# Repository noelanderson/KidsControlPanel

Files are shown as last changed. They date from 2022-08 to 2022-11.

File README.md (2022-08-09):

# KidsControlPanel
Octonaut's inspired vehicle control panel with flight yoke and standard instruments

Javascript application runs instrument cluster on Raspberry Pi displaying on a (800x400) lcd panel

Custom RP2040 based hardware runs the remaining panel functions

RP2040 board appears as a HID joystick and uses a VL6180X ranging sensor to measure pitch, and an AS5600 magnetic Rotation Sensor to measure roll.

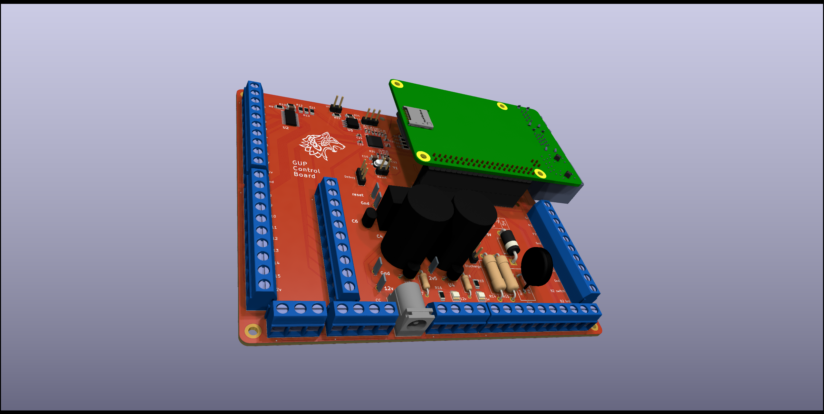
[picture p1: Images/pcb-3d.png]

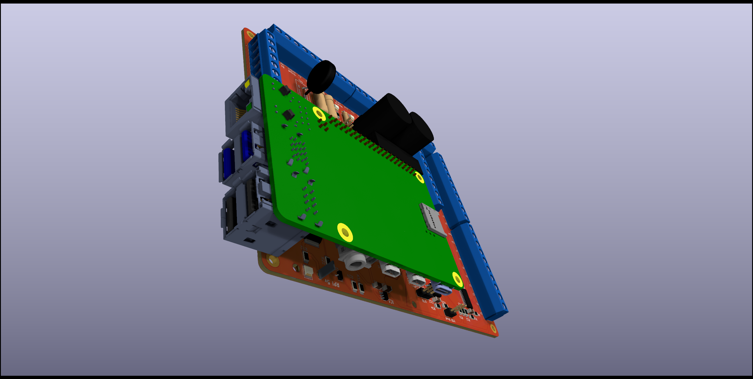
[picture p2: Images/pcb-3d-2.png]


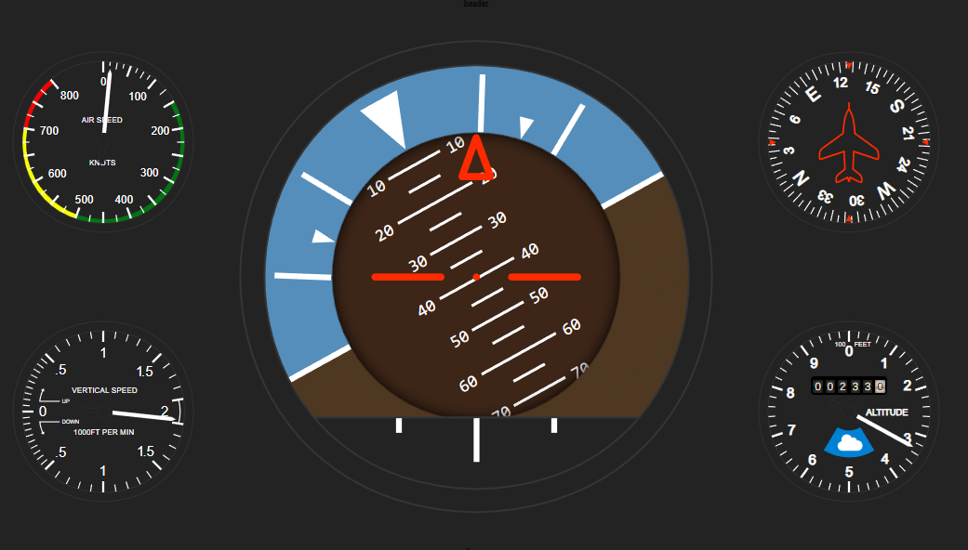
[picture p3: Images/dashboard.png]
dashboard


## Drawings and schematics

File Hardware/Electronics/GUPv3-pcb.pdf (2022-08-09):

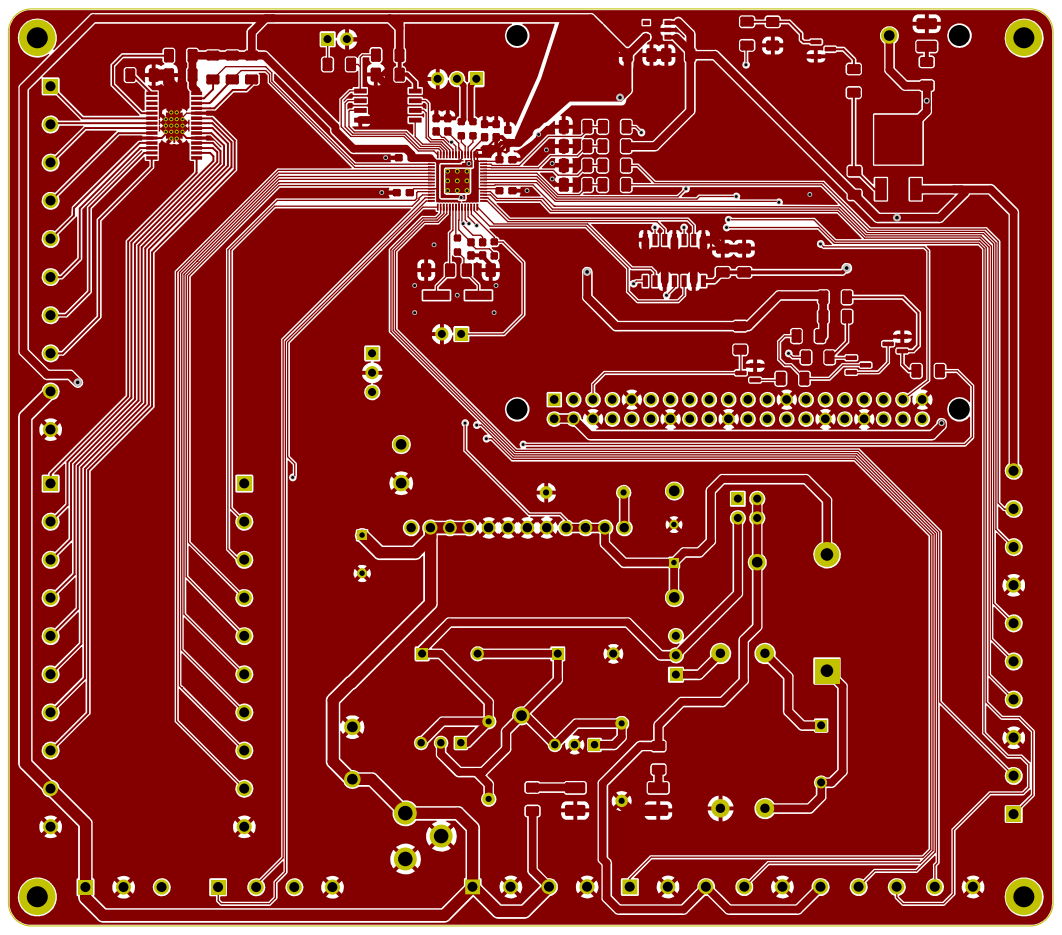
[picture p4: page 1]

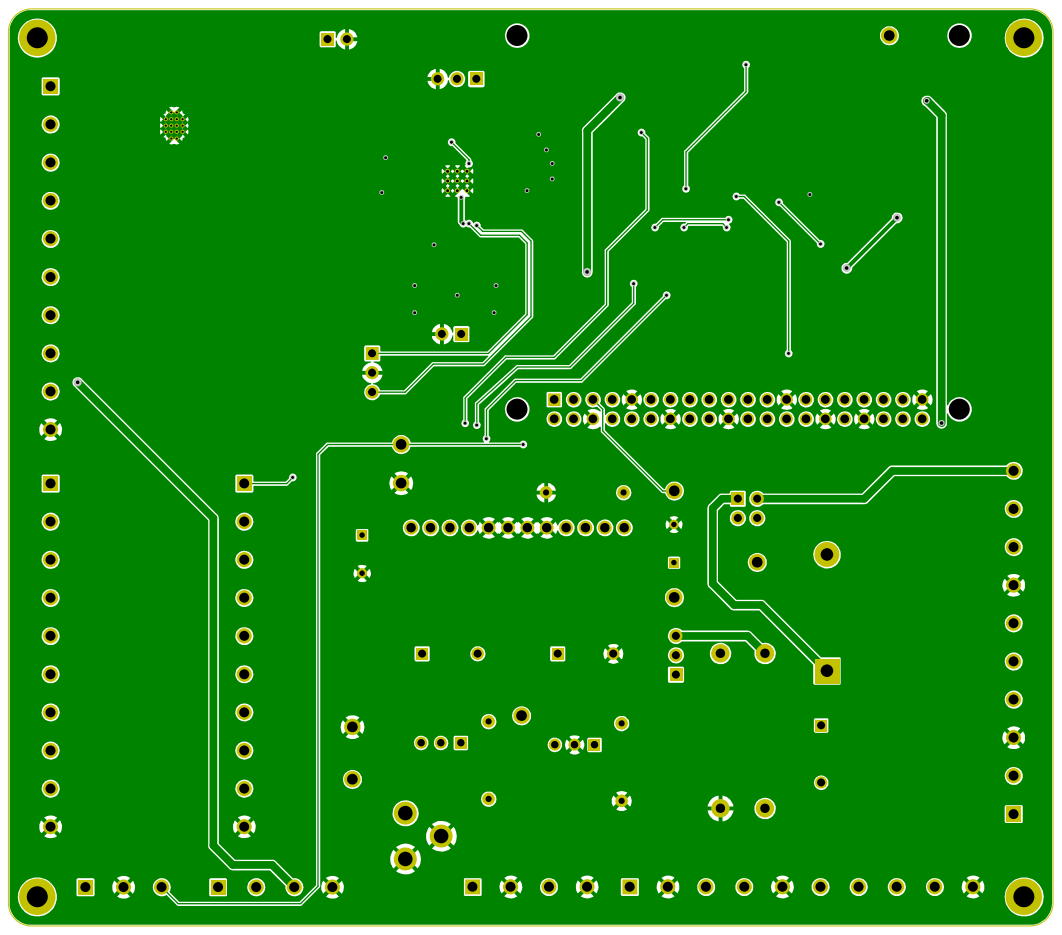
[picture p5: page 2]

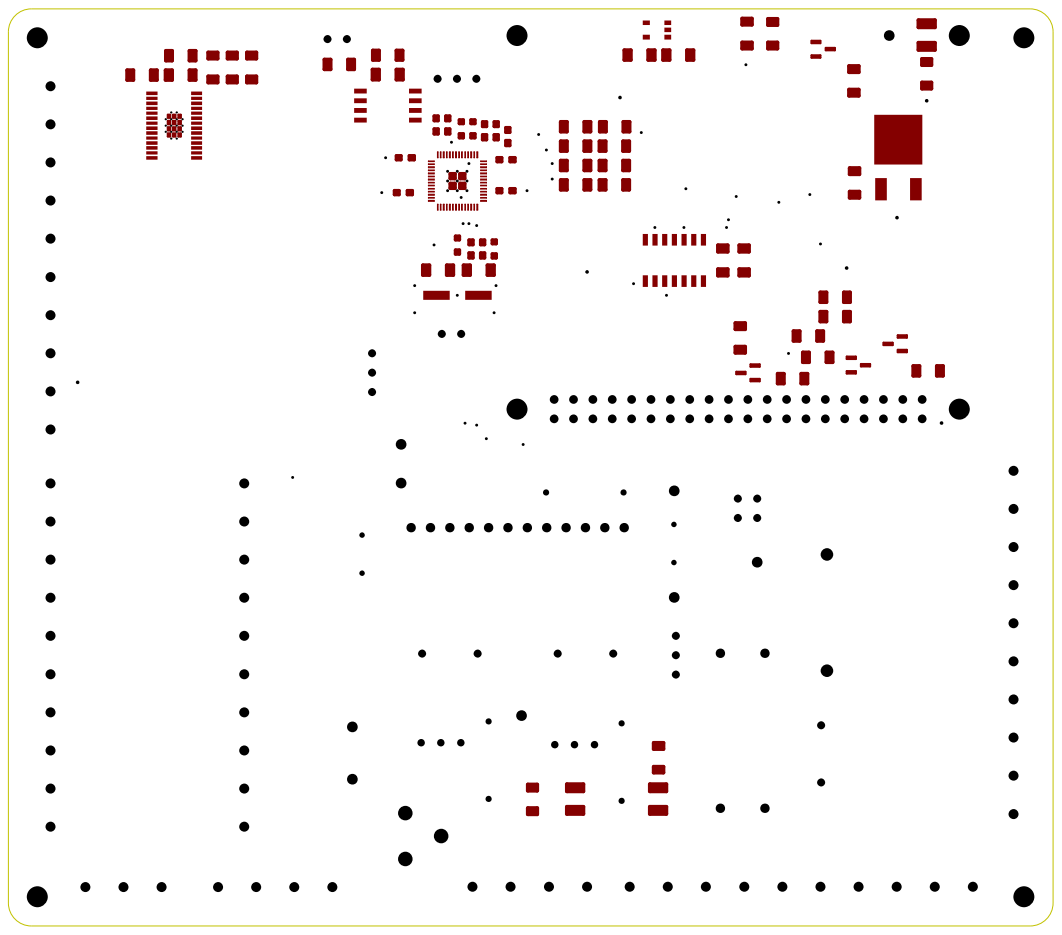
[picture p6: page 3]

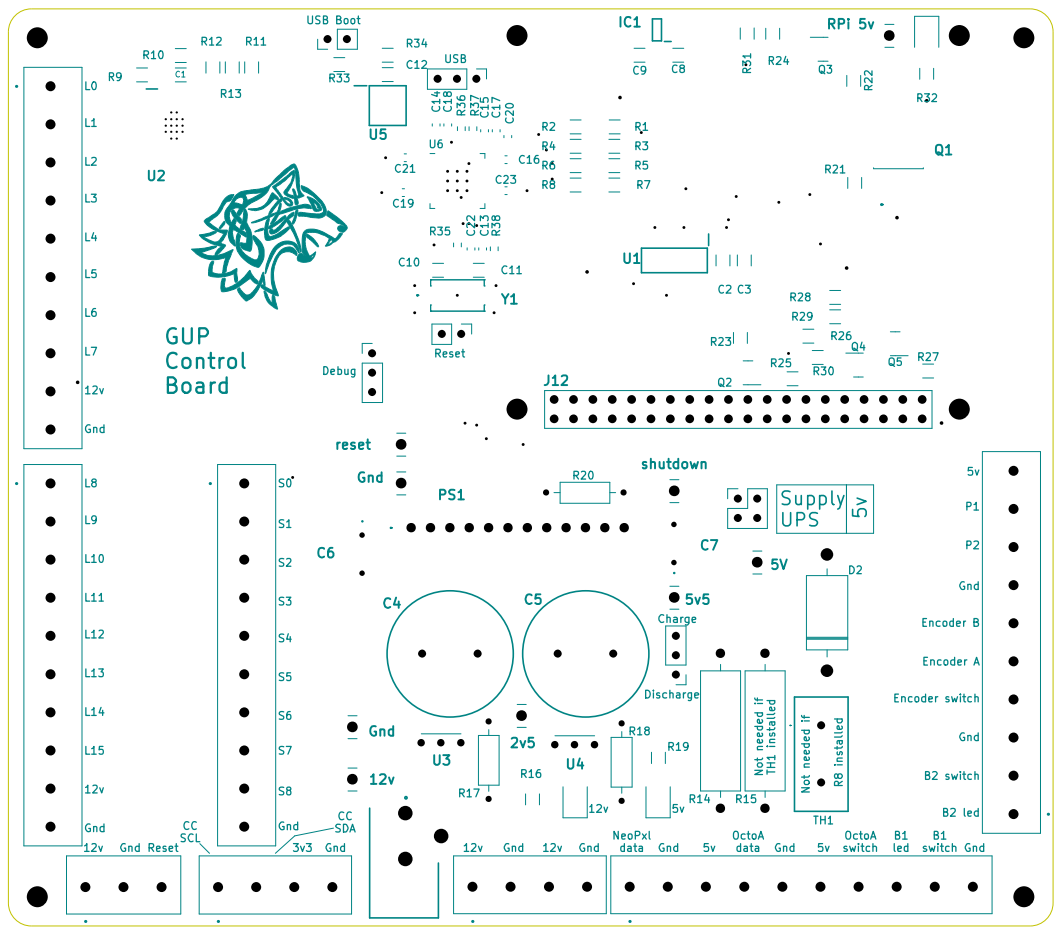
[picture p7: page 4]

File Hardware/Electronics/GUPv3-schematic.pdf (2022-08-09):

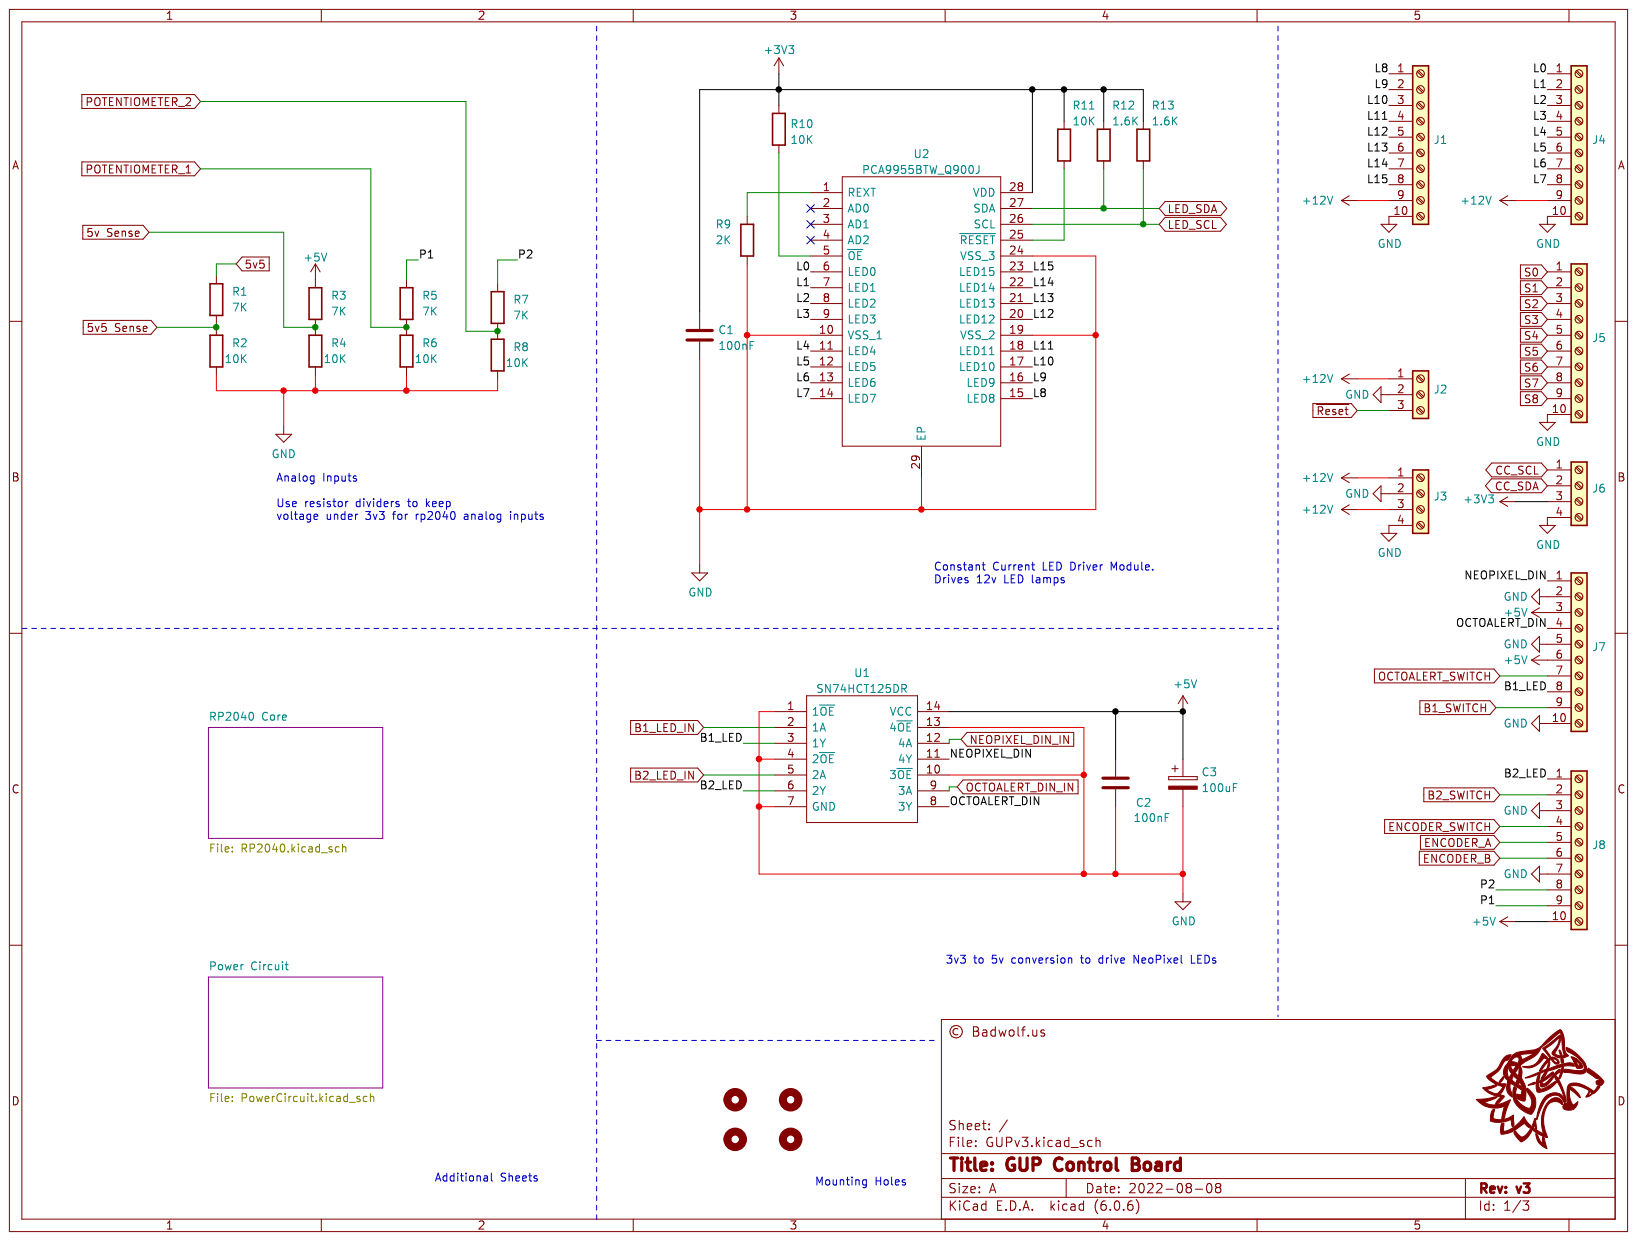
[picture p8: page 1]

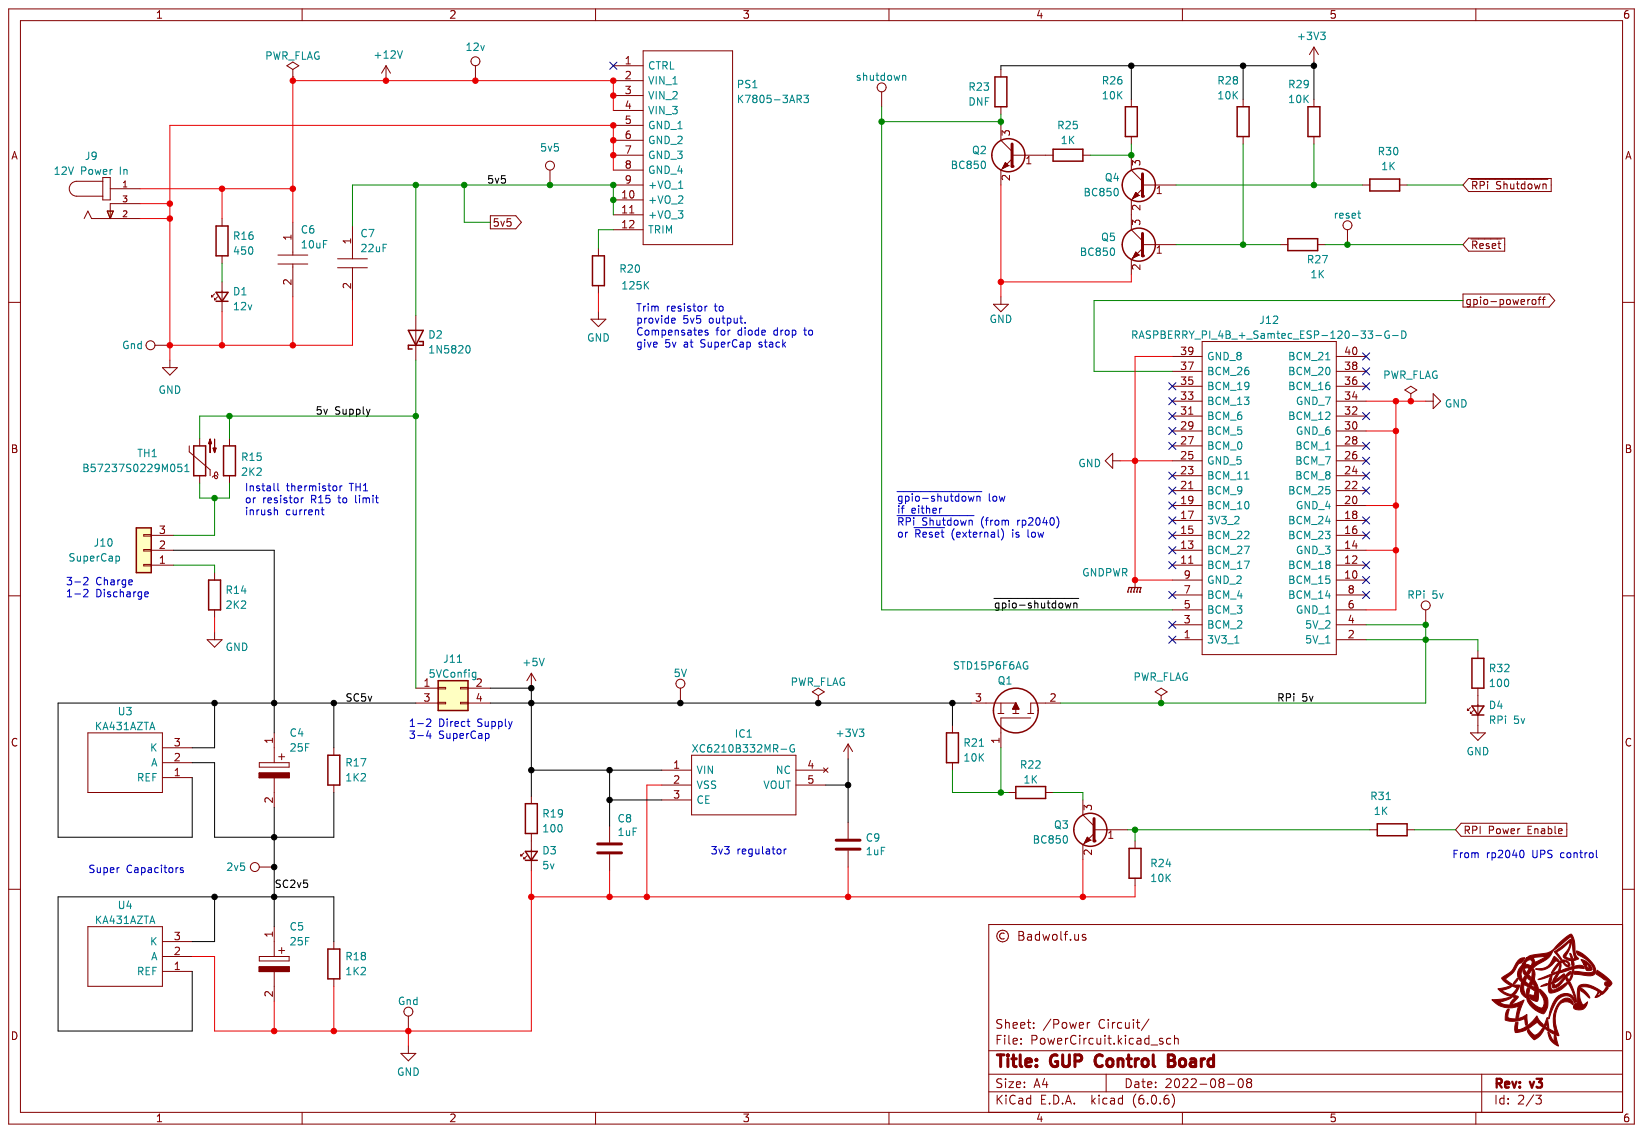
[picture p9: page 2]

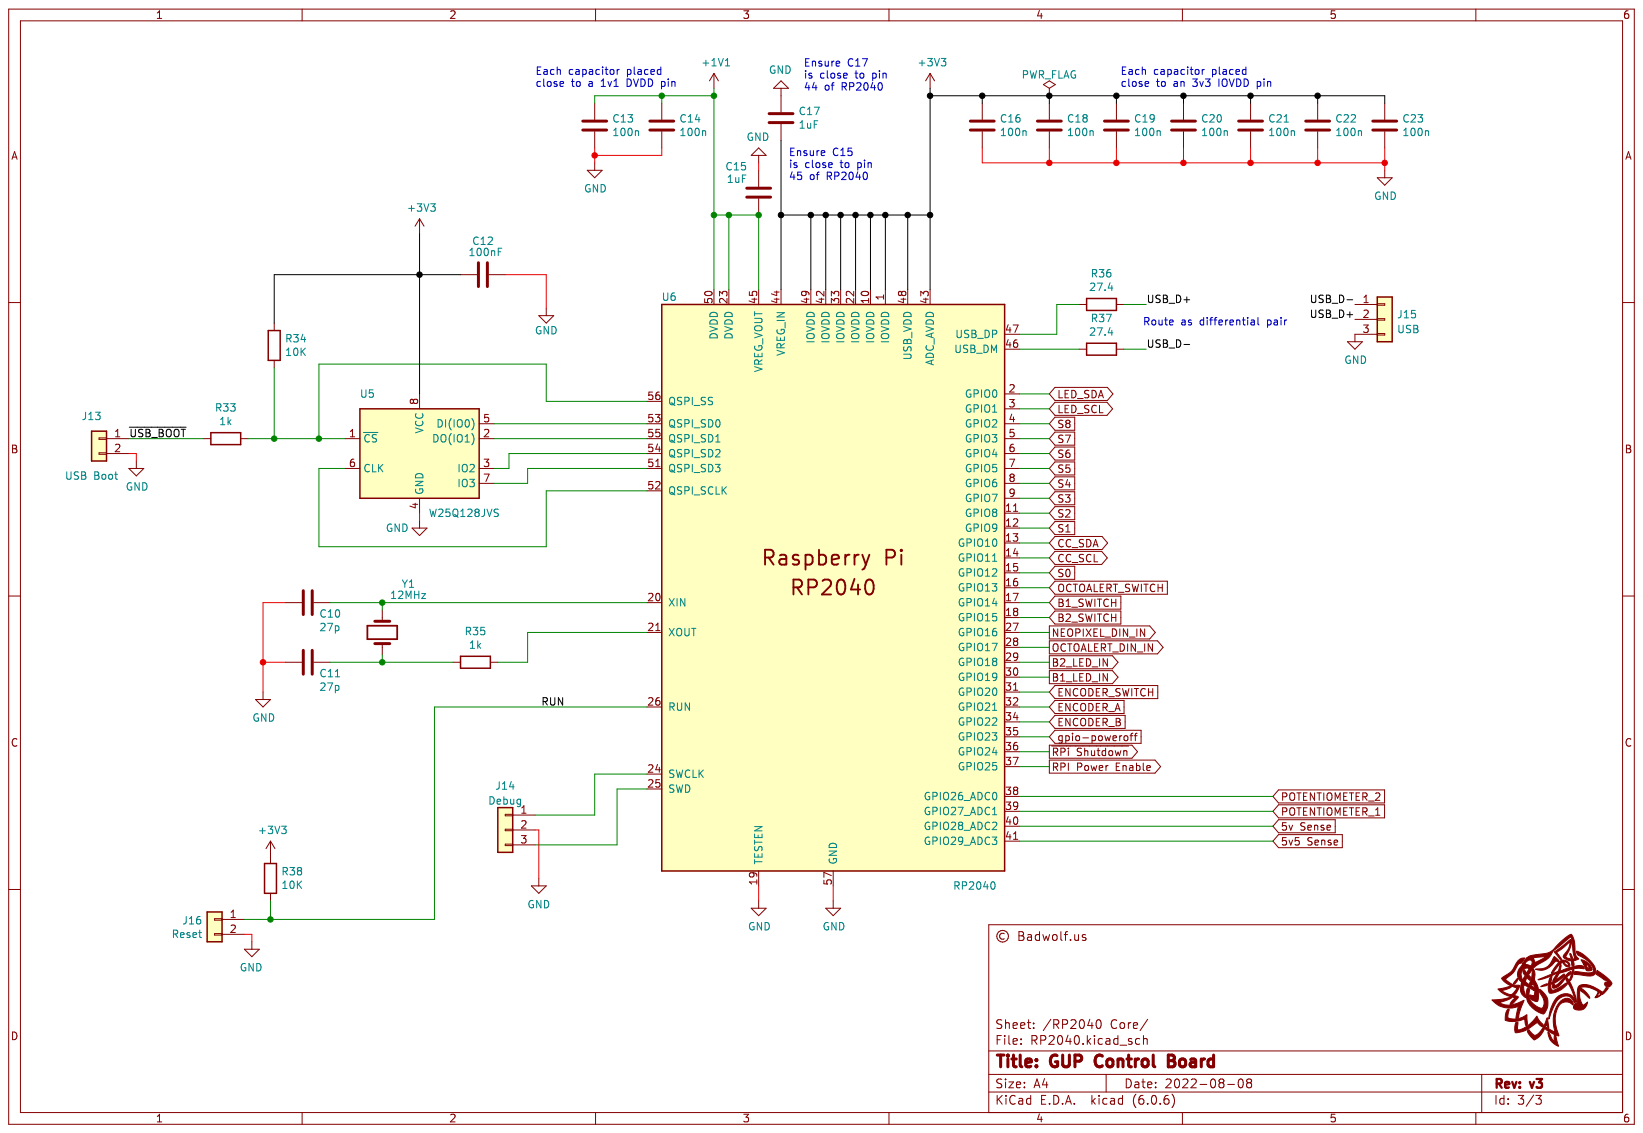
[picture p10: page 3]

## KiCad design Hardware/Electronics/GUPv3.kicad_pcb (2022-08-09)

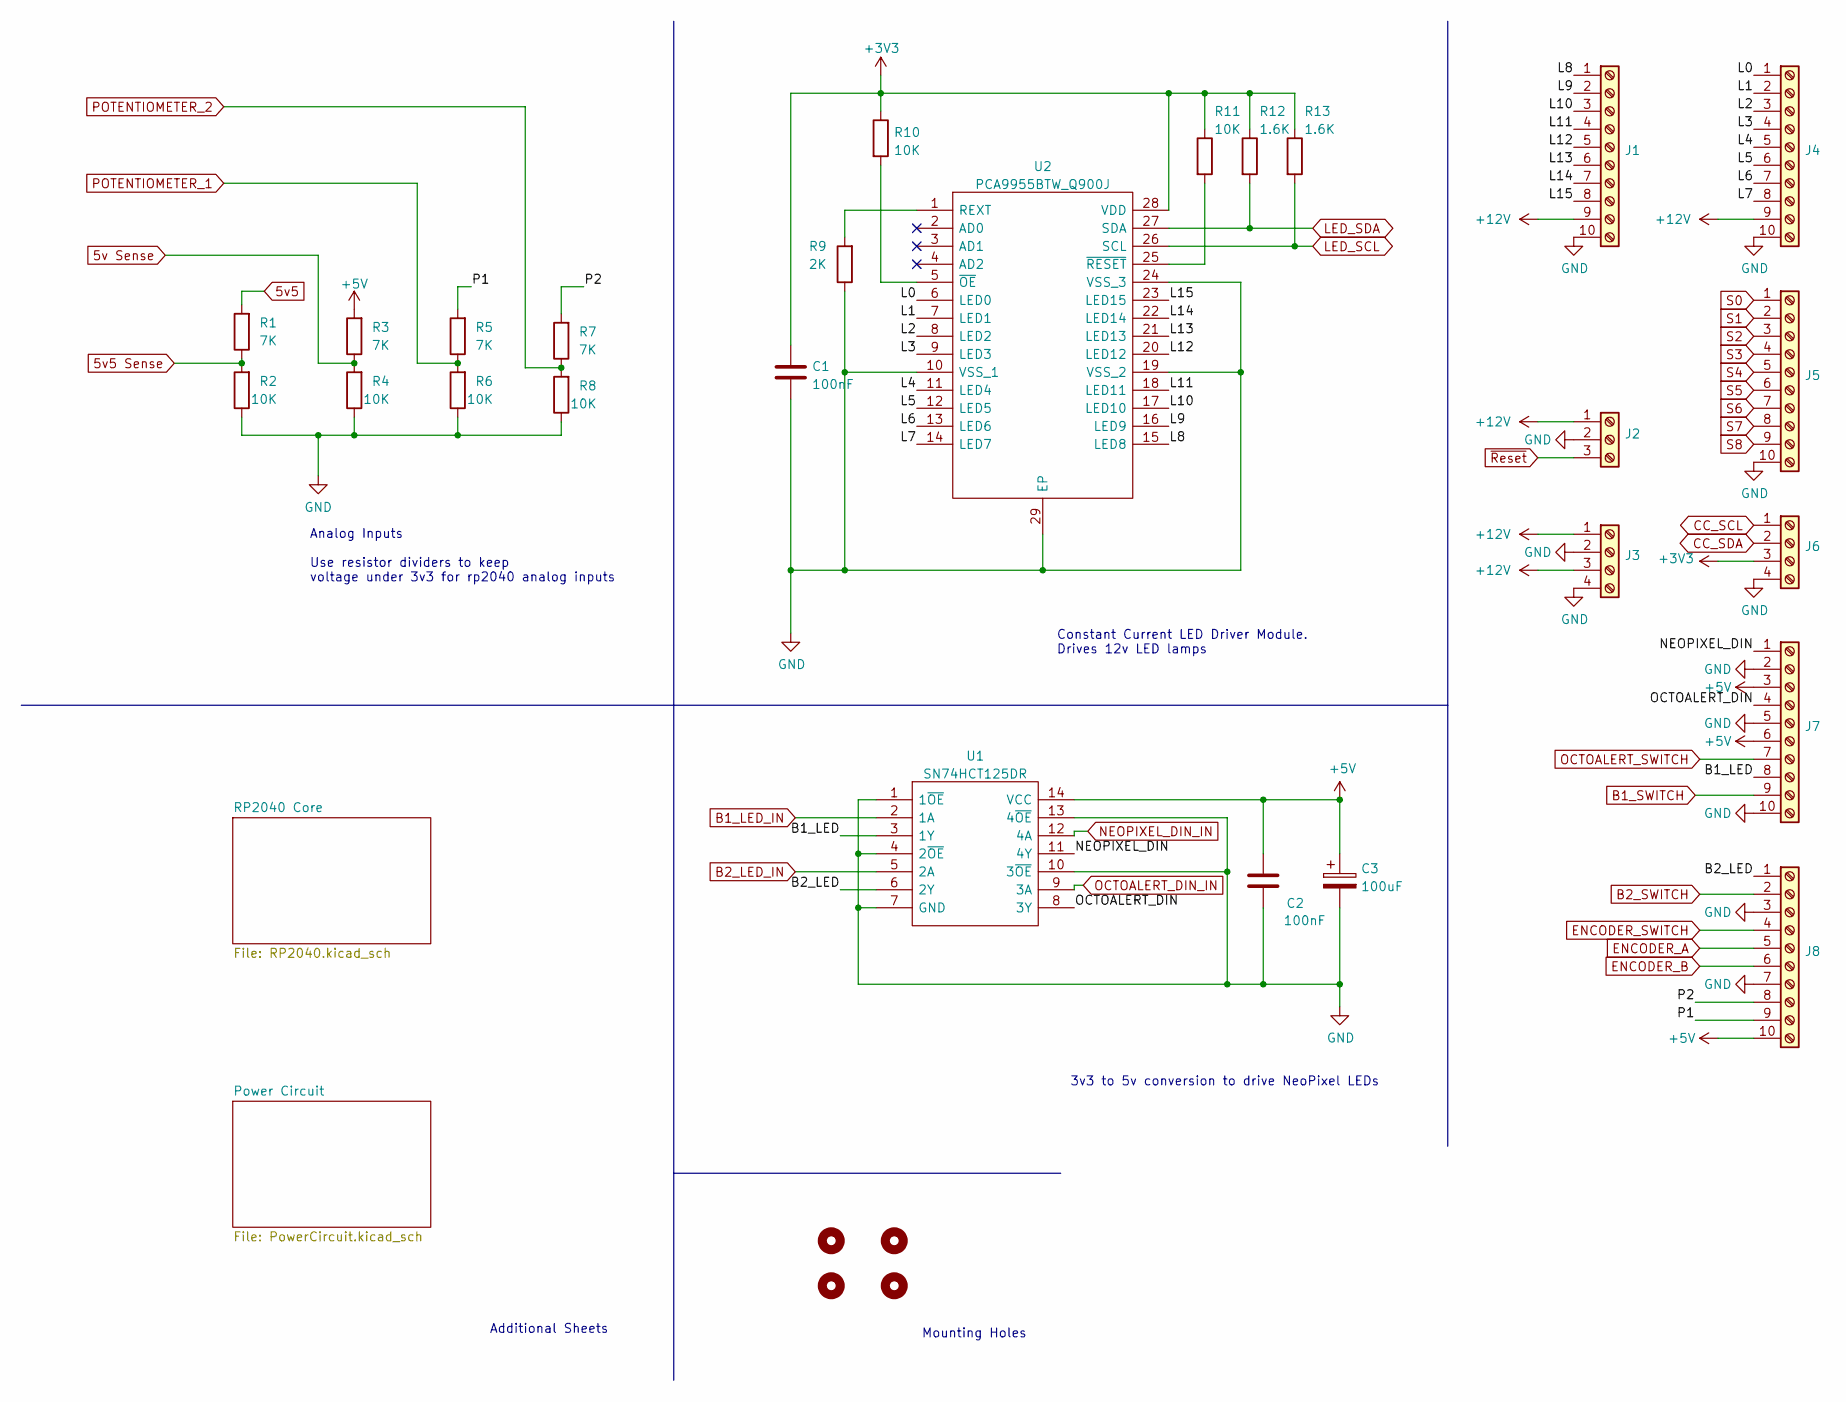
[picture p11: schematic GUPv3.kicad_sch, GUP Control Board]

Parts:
C1, C2: 100nF; C_1206_3216Metric_Pad1.33x1.80mm_HandSolder
C3: 100uF; C_1206_3216Metric_Pad1.33x1.80mm_HandSolder
H1, H2, H3, H4: M2.5; MountingHole_2.7mm_M2.5_DIN965_Pad
J1, J4, J5, J7, J8: Screw_Terminal_01x10; CUI_TB002-500-10BE
J2: Screw_Terminal_01x03; CUI_TB002-500-03BE
J3, J6: Screw_Terminal_01x04; CUI_TB002-500-04BE
R1, R3, R5, R7: 7K; R_1206_3216Metric_Pad1.30x1.75mm_HandSolder
R2, R4, R6, R8, R10, R11: 10K; R_1206_3216Metric_Pad1.30x1.75mm_HandSolder
R9: 2K; R_1206_3216Metric_Pad1.30x1.75mm_HandSolder
R12, R13: 1.6K; R_1206_3216Metric_Pad1.30x1.75mm_HandSolder
U1: SN74HCT125DR; SOIC127P600X175-14N; Mouser Part Number 595-SN74HCT125DR
U2: PCA9955BTW_Q900J; SOP65P640X110-29N_thermal_vias; Mouser Part Number 771-PCA9955BTW/Q900J

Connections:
5v5: R1.2; also elsewhere on the board
5v5 Sense: R1.1, R2.2; also elsewhere on the board
5v Sense: R3.1, R4.2; also elsewhere on the board
+3V3: C1.1, J6.3, R10.1, R11.1, R12.1, R13.1, U2.28 (VDD); also elsewhere on the board
+5V: C2.1, C3.1, J7.3, J7.6, J8.10, R3.2, U1.14 (VCC); also elsewhere on the board
+12V: J1.9, J2.1, J3.1, J3.3, J4.9; also elsewhere on the board
/B1_LED: J7.8, U1.3 (1Y)
/B2_LED: J8.1, U1.6 (2Y)
/L0: J4.1, U2.6 (LED0)
/L1: J4.2, U2.7 (LED1)
/L2: J4.3, U2.8 (LED2)
/L3: J4.4, U2.9 (LED3)
/L4: J4.5, U2.11 (LED4)
/L5: J4.6, U2.12 (LED5)
/L6: J4.7, U2.13 (LED6)
/L7: J4.8, U2.14 (LED7)
/L8: J1.1, U2.15 (LED8)
/L9: J1.2, U2.16 (LED9)
/L10: J1.3, U2.17 (LED10)
/L11: J1.4, U2.18 (LED11)
/L12: J1.5, U2.20 (LED12)
/L13: J1.6, U2.21 (LED13)
/L14: J1.7, U2.22 (LED14)
/L15: J1.8, U2.23 (LED15)
/NEOPIXEL_DIN: J7.1, U1.11 (4Y)
/OCTOALERT_DIN: J7.4, U1.8 (3Y)
/P1: J8.9, R5.2
/P2: J8.8, R7.2
B1_LED_IN: U1.2 (1A); also elsewhere on the board
B1_SWITCH: J7.9; also elsewhere on the board
B2_LED_IN: U1.5 (2A); also elsewhere on the board
B2_SWITCH: J8.2; also elsewhere on the board
CC_SCL: J6.1; also elsewhere on the board
CC_SDA: J6.2; also elsewhere on the board
ENCODER_A: J8.5; also elsewhere on the board
ENCODER_B: J8.6; also elsewhere on the board
ENCODER_SWITCH: J8.4; also elsewhere on the board
GND: C1.2, C2.2, C3.2, J1.10, J2.2, J3.2, J3.4, J4.10, J5.10, J6.4, J7.2, J7.5, J7.10, J8.3, J8.7, R2.1, R4.1, R6.1, R8.1, R9.1, U1.1 (1~OE), U1.4 (2~OE), U1.7 (GND), U1.10 (3~OE), U1.13 (4~OE), U2.10 (VSS_1), U2.19 (VSS_2), U2.24 (VSS_3), U2.29 (EP); also elsewhere on the board
LED_SCL: R13.2, U2.26 (SCL); also elsewhere on the board
LED_SDA: R12.2, U2.27 (SDA); also elsewhere on the board
NEOPIXEL_DIN_IN: U1.12 (4A); also elsewhere on the board
unnamed: R9.2, U2.1 (REXT)
unnamed: R10.2, U2.5 (~OE)
unnamed: R11.2, U2.25 (~RESET)
OCTOALERT_DIN_IN: U1.9 (3A); also elsewhere on the board
OCTOALERT_SWITCH: J7.7; also elsewhere on the board
POTENTIOMETER_1: R5.1, R6.2; also elsewhere on the board
POTENTIOMETER_2: R7.1, R8.2; also elsewhere on the board
S0: J5.1; also elsewhere on the board
S1: J5.2; also elsewhere on the board
S2: J5.3; also elsewhere on the board
S3: J5.4; also elsewhere on the board
S4: J5.5; also elsewhere on the board
S5: J5.6; also elsewhere on the board
S6: J5.7; also elsewhere on the board
S7: J5.8; also elsewhere on the board
S8: J5.9; also elsewhere on the board
~Reset: J2.3; also elsewhere on the board

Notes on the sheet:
3v3 to 5v conversion to drive NeoPixel LEDs
Analog Inputs Use resistor dividers to keep voltage under 3v3 for rp2040 analog inputs
Constant Current LED Driver Module. Drives 12v LED lamps
Additional Sheets
Mounting Holes

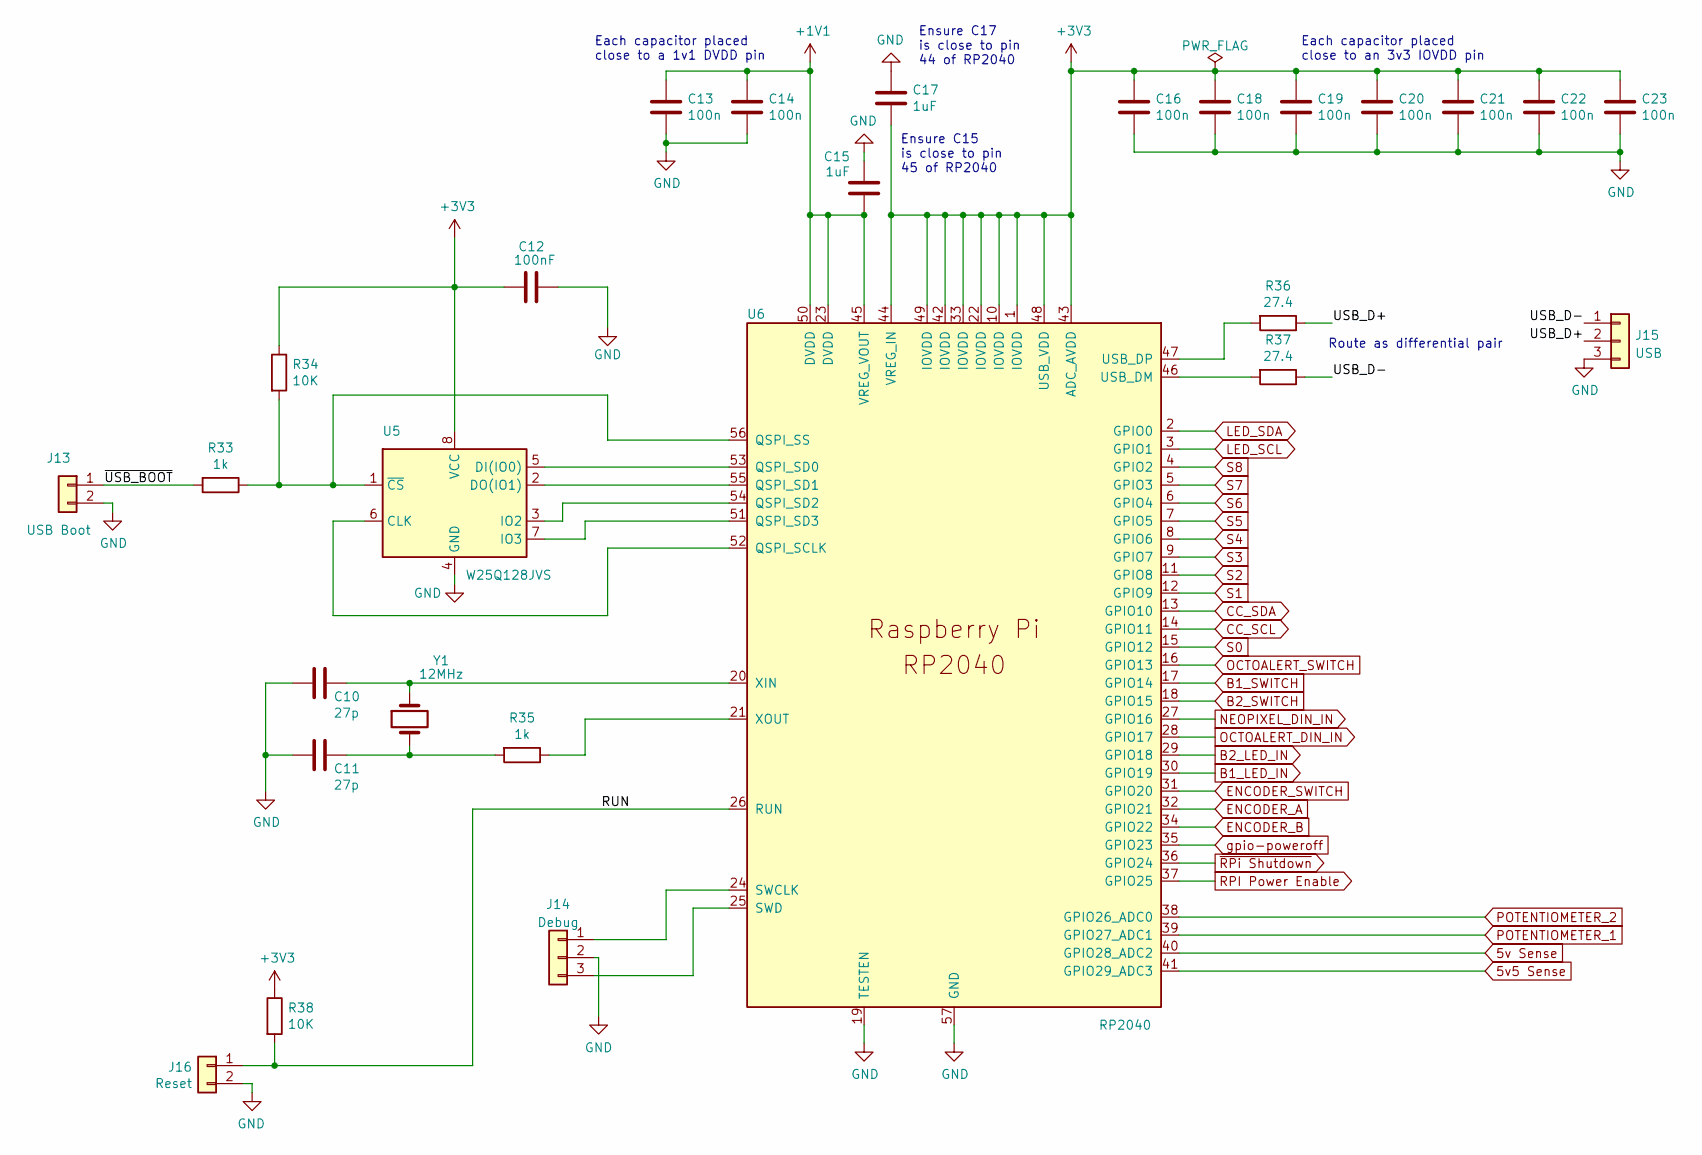
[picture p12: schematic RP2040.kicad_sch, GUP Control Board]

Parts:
C10, C11: 27p; C_1206_3216Metric_Pad1.33x1.80mm_HandSolder
C12: 100nF; C_1206_3216Metric_Pad1.33x1.80mm_HandSolder
C13, C14, C16, C18, C19, C20, C21, C22, C23: 100n; C_0603_1608Metric_Pad1.08x0.95mm_HandSolder
C15, C17: 1uF; C_0603_1608Metric_Pad1.08x0.95mm_HandSolder
J13: USB Boot; PinHeader_1x02_P2.54mm_Vertical
J14: Debug; PinHeader_1x03_P2.54mm_Vertical
J15: USB; PinHeader_1x03_P2.54mm_Vertical
J16: Reset; PinHeader_1x02_P2.54mm_Vertical
R33: 1k; R_1206_3216Metric_Pad1.30x1.75mm_HandSolder
R34: 10K; R_1206_3216Metric_Pad1.30x1.75mm_HandSolder
R35: 1k; R_0603_1608Metric_Pad0.98x0.95mm_HandSolder
R36, R37: 27.4; R_0603_1608Metric_Pad0.98x0.95mm_HandSolder
R38: 10K; R_0603_1608Metric_Pad0.98x0.95mm_HandSolder
U5: W25Q128JVS; SOIC127P790X216-8N
U6: RP2040; RP2040-QFN-56
Y1: 12MHz; ABLS7M216000MHZD2YT; Digi-Key_PN 535-13415-1-ND

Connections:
5v5 Sense: U6.41 (GPIO29_ADC3); also elsewhere on the board
5v Sense: U6.40 (GPIO28_ADC2); also elsewhere on the board
+1V1: C13.1, C14.1, C15.1, U6.23 (DVDD), U6.45 (VREG_VOUT), U6.50 (DVDD)
+3V3: C12.2, C16.1, C17.2, C18.1, C19.1, C20.1, C21.1, C22.1, C23.1, R34.1, R38.1, U5.8 (VCC), U6.1 (IOVDD), U6.10 (IOVDD), U6.22 (IOVDD), U6.33 (IOVDD), U6.42 (IOVDD), U6.43 (ADC_AVDD), U6.44 (VREG_IN), U6.48 (USB_VDD), U6.49 (IOVDD); also elsewhere on the board
/RP2040 Core/RUN: J16.1, R38.2, U6.26 (RUN)
/RP2040 Core/USB_D+: J15.2, R36.1
/RP2040 Core/USB_D-: J15.1, R37.1
/RP2040 Core/~USB_BOOT: J13.1, R33.2
B1_LED_IN: U6.30 (GPIO19); also elsewhere on the board
B1_SWITCH: U6.17 (GPIO14); also elsewhere on the board
B2_LED_IN: U6.29 (GPIO18); also elsewhere on the board
B2_SWITCH: U6.18 (GPIO15); also elsewhere on the board
CC_SCL: U6.14 (GPIO11); also elsewhere on the board
CC_SDA: U6.13 (GPIO10); also elsewhere on the board
ENCODER_A: U6.32 (GPIO21); also elsewhere on the board
ENCODER_B: U6.34 (GPIO22); also elsewhere on the board
ENCODER_SWITCH: U6.31 (GPIO20); also elsewhere on the board
GND: C10.2, C11.2, C12.1, C13.2, C14.2, C15.2, C16.2, C17.1, C18.2, C19.2, C20.2, C21.2, C22.2, C23.2, J13.2, J14.2, J15.3, J16.2, U5.4 (GND), U6.19 (TESTEN), U6.57 (GND); also elsewhere on the board
LED_SCL: U6.3 (GPIO1); also elsewhere on the board
LED_SDA: U6.2 (GPIO0); also elsewhere on the board
NEOPIXEL_DIN_IN: U6.27 (GPIO16); also elsewhere on the board
unnamed: C10.1, U6.20 (XIN), Y1.1
unnamed: C11.1, R35.2, Y1.2
unnamed: J14.1, U6.24 (SWCLK)
unnamed: J14.3, U6.25 (SWD)
unnamed: R33.1, R34.2, U5.1 (~CS), U6.56 (QSPI_SS)
unnamed: R35.1, U6.21 (XOUT)
unnamed: R36.2, U6.47 (USB_DP)
unnamed: R37.2, U6.46 (USB_DM)
unnamed: U5.2 (DO(IO1)), U6.55 (QSPI_SD1)
unnamed: U5.3 (IO2), U6.54 (QSPI_SD2)
unnamed: U5.5 (DI(IO0)), U6.53 (QSPI_SD0)
unnamed: U5.6 (CLK), U6.52 (QSPI_SCLK)
unnamed: U5.7 (IO3), U6.51 (QSPI_SD3)
OCTOALERT_DIN_IN: U6.28 (GPIO17); also elsewhere on the board
OCTOALERT_SWITCH: U6.16 (GPIO13); also elsewhere on the board
POTENTIOMETER_1: U6.39 (GPIO27_ADC1); also elsewhere on the board
POTENTIOMETER_2: U6.38 (GPIO26_ADC0); also elsewhere on the board
RPI Power Enable: U6.37 (GPIO25); also elsewhere on the board
S0: U6.15 (GPIO12); also elsewhere on the board
S1: U6.12 (GPIO9); also elsewhere on the board
S2: U6.11 (GPIO8); also elsewhere on the board
S3: U6.9 (GPIO7); also elsewhere on the board
S4: U6.8 (GPIO6); also elsewhere on the board
S5: U6.7 (GPIO5); also elsewhere on the board
S6: U6.6 (GPIO4); also elsewhere on the board
S7: U6.5 (GPIO3); also elsewhere on the board
S8: U6.4 (GPIO2); also elsewhere on the board
gpio-poweroff: U6.35 (GPIO23); also elsewhere on the board
~RPi Shutdown: U6.36 (GPIO24); also elsewhere on the board

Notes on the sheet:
Route as differential pair
Ensure C15 is close to pin 45 of RP2040
Each capacitor placed close to an 3v3 IOVDD pin
Ensure C17 is close to pin 44 of RP2040
Each capacitor placed close to a 1v1 DVDD pin

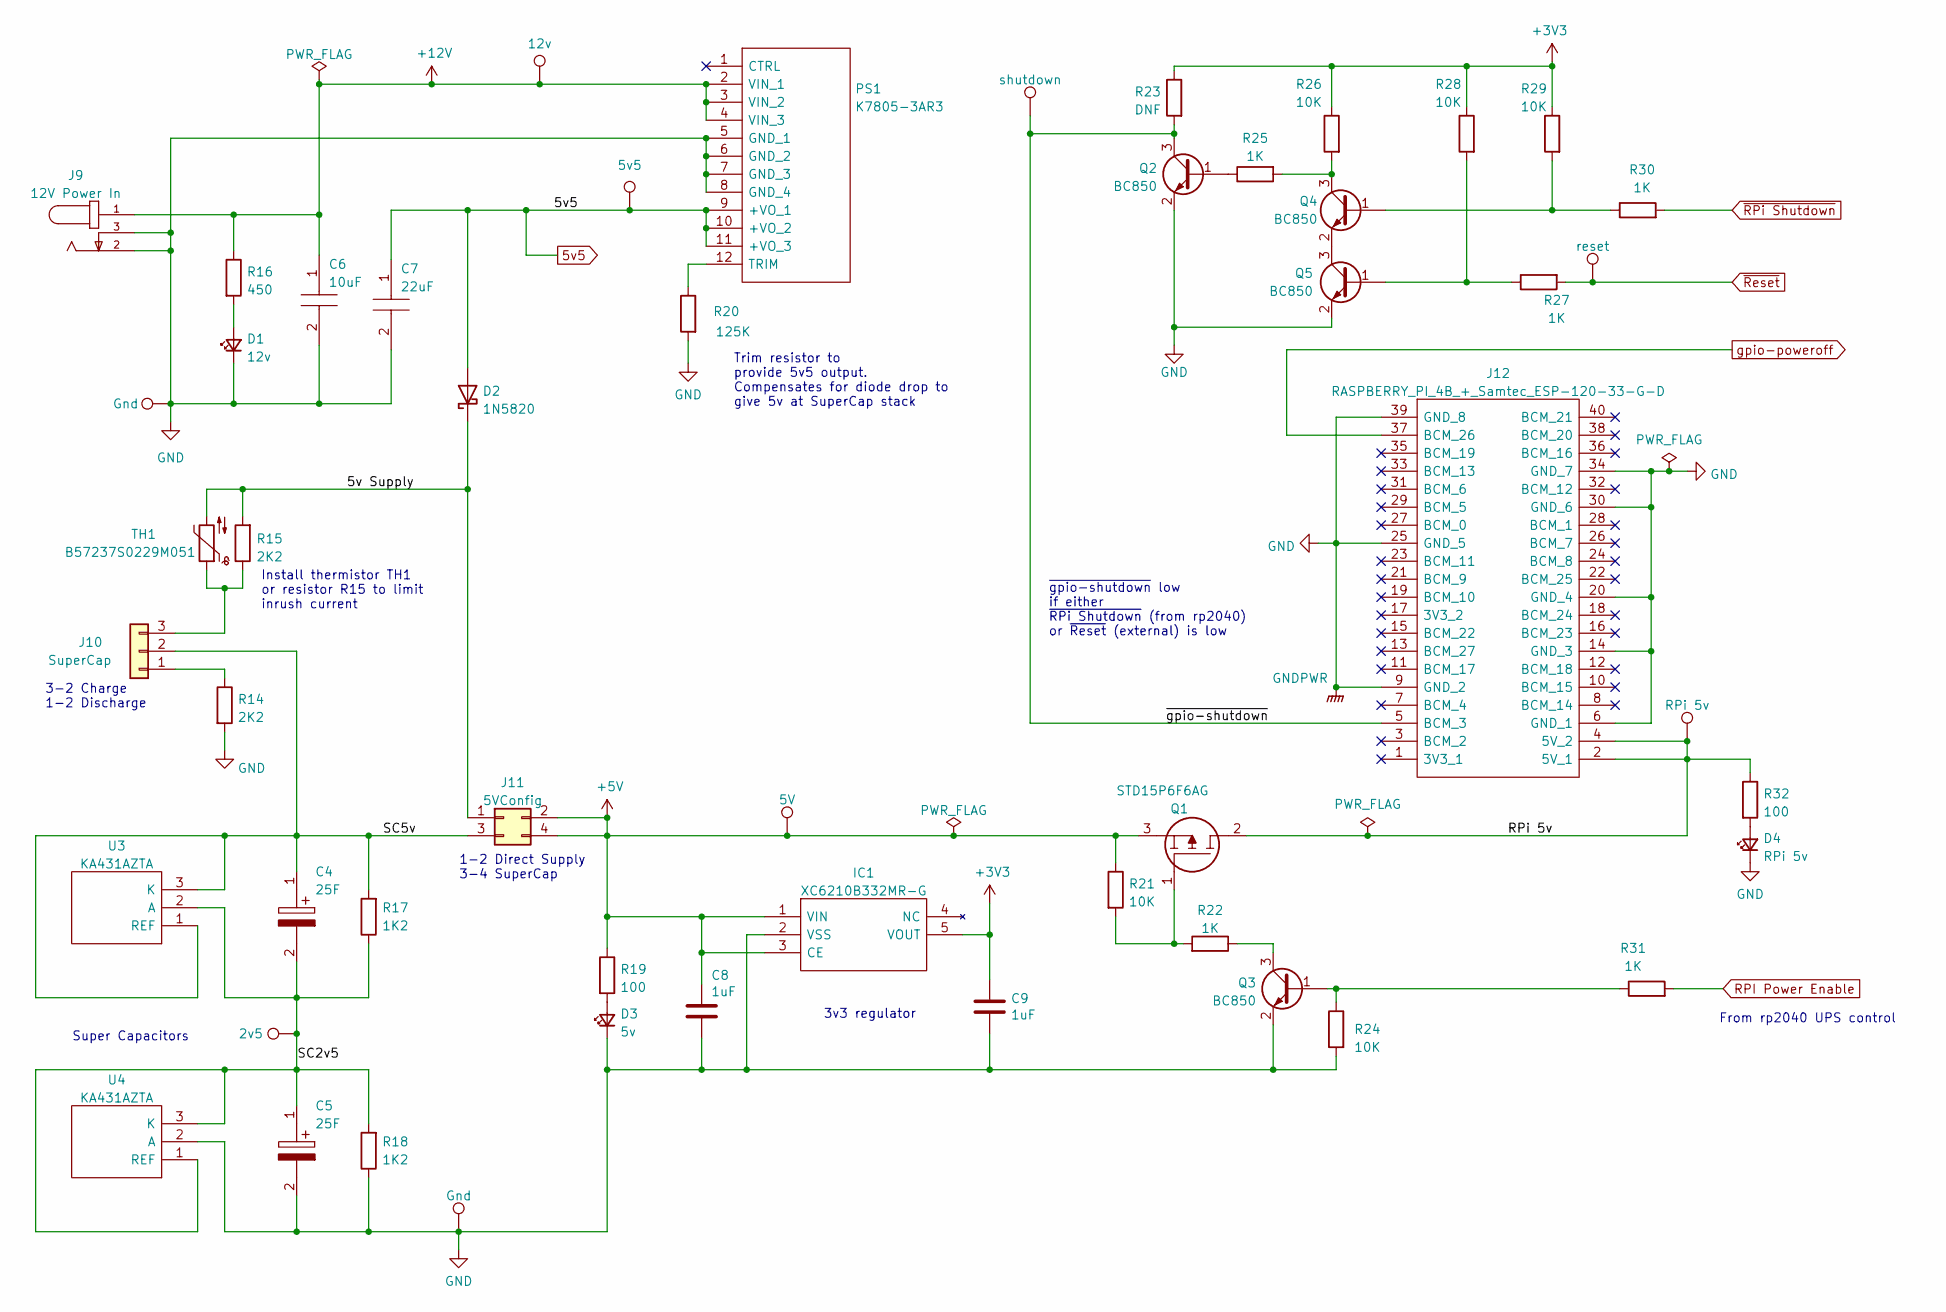
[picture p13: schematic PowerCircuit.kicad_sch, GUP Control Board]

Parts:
C4, C5: 25F; CAPPRD730W85D1650H2700; Mouser Part Number 581-SCCU25B256SRB
C6: 10uF; FG20; Mouser Part Number 810-FG20X7S1H106KRT6
C7: 22uF; FK20; Mouser Part Number N/A
C8, C9: 1uF; C_1206_3216Metric_Pad1.33x1.80mm_HandSolder
D1: 12v; LED_1210_3225Metric_Pad1.42x2.65mm_HandSolder
D2: 1N5820; D_DO-201AD_P15.24mm_Horizontal
D3: 5v; LED_1210_3225Metric_Pad1.42x2.65mm_HandSolder
D4: RPi 5v; LED_1210_3225Metric_Pad1.42x2.65mm_HandSolder
IC1: XC6210B332MR-G; SOT95P280X130-5N; Mouser Part Number 865-XC6210B332MR-G
J9: 12V Power In; PJ-102AH; PART_REV 1.02
J10: SuperCap; PinHeader_1x03_P2.54mm_Vertical
J11: 5VConfig; PinHeader_2x02_P2.54mm_Vertical
J12: RASPBERRY_PI_4B_+_Samtec_ESP-120-33-G-D; RASPBERRYPI4B4GB; Manufacturer_Part_Number RASPBERRY PI 4B + Samtec ESP-120-33-G-D
PS1: K7805-3AR3; K78053AR3; Manufacturer_Part_Number K7805-3AR3
Q1: STD15P6F6AG; STD36P4LLF6; Mouser Part Number 511-STD15P6F6AG
Q2, Q3, Q4, Q5: BC850; SOT-23
R14, R15: 2K2; R_Axial_DIN0516_L15.5mm_D5.0mm_P20.32mm_Horizontal
R16: 450; R_1206_3216Metric_Pad1.30x1.75mm_HandSolder
R17, R18: 1K2; R_Axial_DIN0207_L6.3mm_D2.5mm_P10.16mm_Horizontal
R19, R32: 100; R_1206_3216Metric_Pad1.30x1.75mm_HandSolder
R20: 125K; R_Axial_DIN0207_L6.3mm_D2.5mm_P10.16mm_Horizontal
R21, R24, R26, R28, R29: 10K; R_1206_3216Metric_Pad1.30x1.75mm_HandSolder
R22, R25, R27, R30, R31: 1K; R_1206_3216Metric_Pad1.30x1.75mm_HandSolder
R23: DNF; R_1206_3216Metric_Pad1.30x1.75mm_HandSolder
TH1: B57237S0229M051
TP1, TP4: Gnd; 4952
TP2: 2v5; 4952
TP3: 12v; 4952
TP5: 5v5; 4952
TP6: 5V; 4952
TP7: shutdown; 4952
TP8: reset; 4952
TP9: RPi 5v; 4952
U3, U4: KA431AZTA; Mouser Part Number 512-KA431AZTA

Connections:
5v5: C7.1, D2.2 (A), PS1.9 (+VO_1), PS1.10 (+VO_2), PS1.11 (+VO_3), TP5.1; also elsewhere on the board
+3V3: C9.1, IC1.5 (VOUT), R23.1, R26.1, R28.1, R29.1; also elsewhere on the board
+5V: C8.1, IC1.1 (VIN), IC1.3 (CE), J11.2, J11.4, Q1.3, R19.1, R21.1, TP6.1; also elsewhere on the board
+12V: C6.1, J9.1, PS1.2 (VIN_1), PS1.3 (VIN_2), PS1.4 (VIN_3), R16.1, TP3.1; also elsewhere on the board
/Power Circuit/5v Supply: D2.1 (K), J11.1, R15.2, TH1.2
/Power Circuit/RPi 5v: J12.2 (5V_1), J12.4 (5V_2), Q1.2, R32.1, TP9.1
/Power Circuit/SC2v5: C4.2, C5.1, R17.1, R18.2, TP2.1, U3.2 (A), U4.1 (REF), U4.3 (K)
/Power Circuit/SC5v: C4.1, J10.2, J11.3, R17.2, U3.1 (REF), U3.3 (K)
/Power Circuit/~gpio-shutdown: J12.5 (BCM_3), Q2.3 (C), R23.2, TP7.1
GND: C5.2, C6.2, C7.2, C8.2, C9.2, D1.1 (K), D3.1 (K), D4.1 (K), IC1.2 (VSS), J9.2, J9.3, J12.6 (GND_1), J12.9 (GND_2), J12.14 (GND_3), J12.20 (GND_4), J12.25 (GND_5), J12.30 (GND_6), J12.34 (GND_7), J12.39 (GND_8), PS1.5 (GND_1), PS1.6 (GND_2), PS1.7 (GND_3), PS1.8 (GND_4), Q2.2 (E), Q3.2 (E), Q5.2 (E), R14.2, R18.1, R20.2, R24.2, TP1.1, TP4.1, U4.2 (A); also elsewhere on the board
unnamed: D1.2 (A), R16.2
unnamed: D3.2 (A), R19.2
unnamed: D4.2 (A), R32.2
unnamed: J10.1, R14.1
unnamed: J10.3, R15.1, TH1.1
unnamed: PS1.12 (TRIM), R20.1
unnamed: Q1.1, R21.2, R22.2
unnamed: Q2.1 (B), R25.1
unnamed: Q3.1 (B), R24.1, R31.1
unnamed: Q3.3 (C), R22.1
unnamed: Q4.1 (B), R29.2, R30.1
unnamed: Q4.2 (E), Q5.3 (C)
unnamed: Q4.3 (C), R25.2, R26.2
unnamed: Q5.1 (B), R27.1, R28.2
RPI Power Enable: R31.2; also elsewhere on the board
gpio-poweroff: J12.37 (BCM_26); also elsewhere on the board
~RPi Shutdown: R30.2; also elsewhere on the board
~Reset: R27.2, TP8.1; also elsewhere on the board

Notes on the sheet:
1-2 Direct Supply 3-4 SuperCap
Trim resistor to provide 5v5 output. Compensates for diode drop to give 5v at SuperCap stack
~{gpio-shutdown} low if either ~{RPi Shutdown} (from rp2040) or ~{Reset} (external) is low
From rp2040 UPS control
Install thermistor TH1 or resistor R15 to limit inrush current
3v3 regulator
Super Capacitors
3-2 Charge 1-2 Discharge

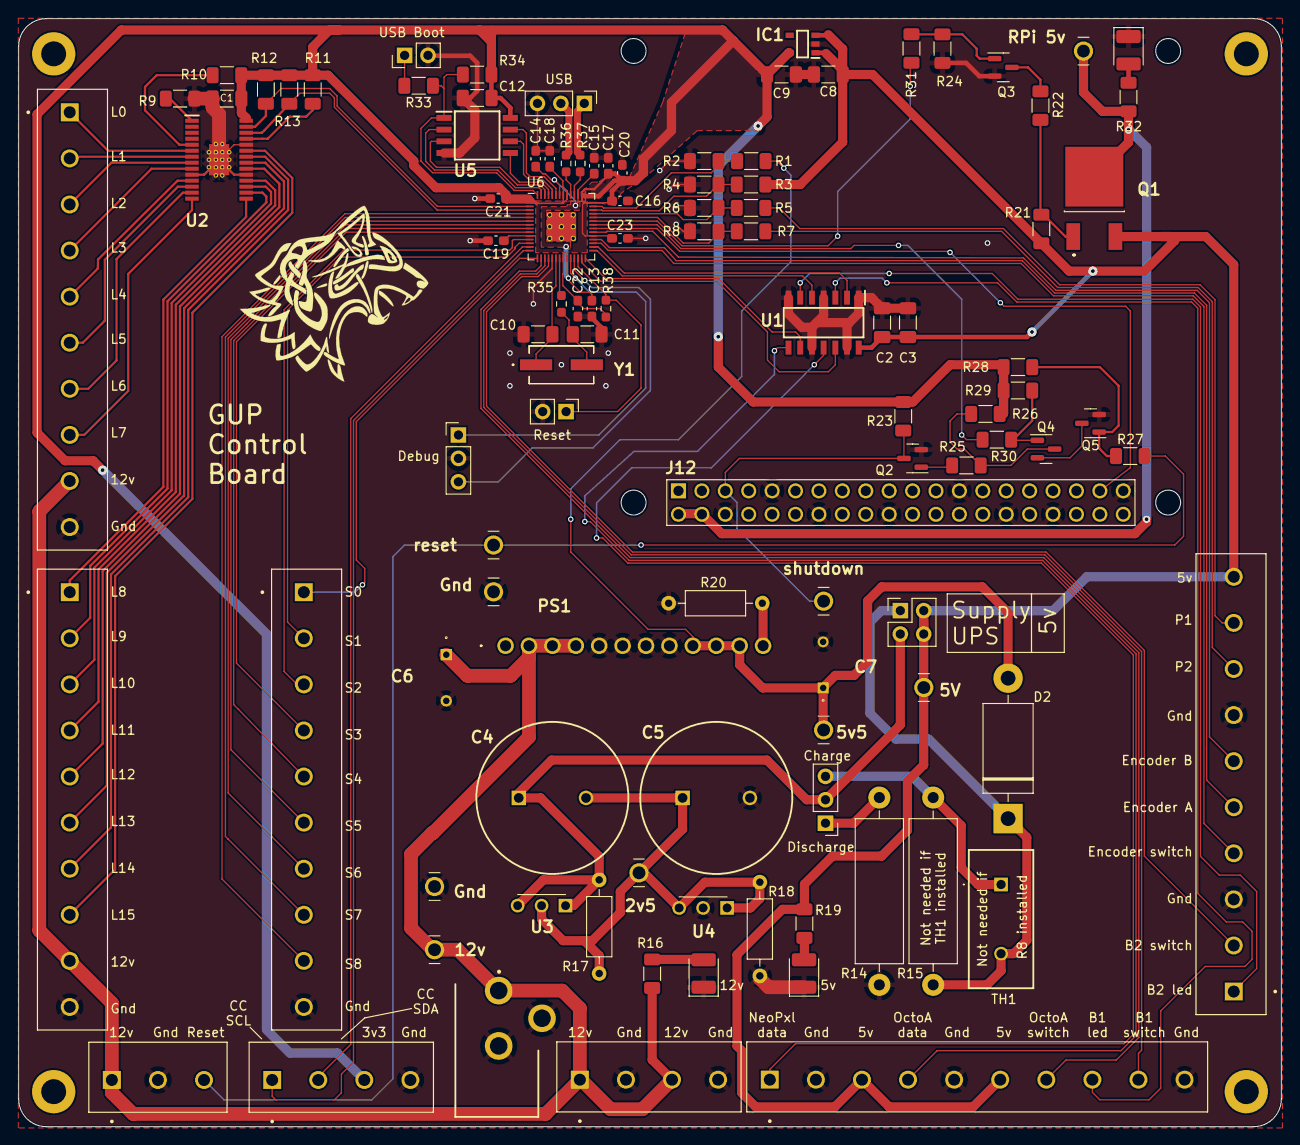
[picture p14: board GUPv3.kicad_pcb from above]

Board: 2 copper layers, 137.0 x 120.2 mm, 109 parts (0 on the bottom side), 98 nets.

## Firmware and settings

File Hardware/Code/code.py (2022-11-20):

import board
import busio
import neopixel
import adafruit_bus_device.i2c_device as i2c_device
import adafruit_vl6180x
import AS5600
import LedArray
import usb_hid
from adafruit_hid.gamepad import Gamepad
from micropython import const
import microcontroller
from microcontroller import watchdog as watchDog
from watchdog import WatchDogMode


class OctoAlert:
    def __init__(self, pin: int):
        self.brightness = 0
        self.pixels = neopixel.NeoPixel(pin, 16)
        self.pixels.fill((255, 165, 0))

    def pulse(self) -> None:
        self.pixels.brightness = (10-abs(10-self.brightness))/10
        self.brightness = (self.brightness + 1) % 20


class MovingAverageFilter:
    def __init__(self, initialValue: int):
        self.buffer = [initialValue] * 8
        self.index = 0

    def update(self, newValue: int) -> int:
        self.buffer[self.index] = newValue
        self.index = (self.index + 1) % 8
        return int(sum(self.buffer) >> 3)


FILTER_ALPHA_POINT2 = const(0x3333)   #(0.2 * 65535)
def ExponentialMovingAverageFilter(new, average, alpha):

    tmp = new * (alpha + 1 ) + average * (65536 - alpha)
    return int((tmp + 32768) / 65536)


octoalert = OctoAlert(board.GP1)
ledArray = LedArray.LedArray(board.GP0)

# Create I2C bus.
i2c = busio.I2C (scl=board.GP15, sda=board.GP14)

'''
# Create time of flight ranging sensor instance.
rangeSensor = adafruit_vl6180x.VL6180X(i2c)
filteredRange = MovingAverageFilter(rangeSensor.range)
OFFSET = const(6) # Min reading from range sensor
MAX = const(106) # Max reading from range sensor
scale = int(round(65536 / (MAX - OFFSET)))
'''

# Create Magnetic Rotation Sensor.
angleSensor = AS5600.AS5600(i2c)
# Set current position as our new zero datum
angleSensor.setZeroPosition(angleSensor.rawAngle)
print(angleSensor.status)
print("MagnetDetected: ", angleSensor.isMagnetDetected)
print("Too Strong: ", angleSensor.isMagnetTooStrong)
print("Too Weak: ", angleSensor.isMagnetTooWeak)

gamePad = Gamepad(usb_hid.devices)

# Setup watchdog
microcontroller.on_next_reset(microcontroller.RunMode.NORMAL)
#watchDog.timeout = 5 # Set a timeout of 5 seconds
#watchDog.mode = WatchDogMode.RESET


loopCount = 0
# Main loop
while True:
    if (loopCount % 400) == 0:
        octoalert.pulse()

    if (loopCount % 4000) == 0:
        ledArray.GameOfLife()

    # Read the range in millimeters and print it.
    if (loopCount % 100) == 0:

        # Read control column angle and scale its output for HID Gamepad input
        # 0 to 90 degrees (0 - 2047 angle reading) = 0 to 127
        # 0 to -90 degrees  (4095 - 3072 angle reading) = 0 to -127
        currentAngle = angleSensor.angle
        if currentAngle <= 2047:
            if currentAngle > 1023:
                currentAngle = 1023
            turn = currentAngle >> 3
        else:
            if currentAngle < 3073:
                currentAngle = 3072
            turn = 0 - (abs(currentAngle - 4095) >> 3)

        # Read control column angle and scale its output for HID Gamepad input
        # -127 to 127
        currentRange = filteredRange.update(rangeSensor.range)
        pitch = (((currentRange - OFFSET) * scale) - 32768) >> 8
        if pitch > 127: pitch = 127
        if pitch < -127: pitch = -127

        #print((pitch, turn))
        gamePad.move_joysticks(x = turn, y = pitch)

    #watchDog.feed()
    loopCount = (loopCount + 1) % 1000000

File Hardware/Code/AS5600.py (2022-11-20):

# SPDX-FileCopyrightText: Copyright (c) 2022 Noel Anderson
#
# SPDX-License-Identifier: MIT
# pylint: disable=line-too-long

"""
`AS5600`
================================================================================
CircuitPython library for connecting an AMS AS5600 12-bit on-axis magnetic rotary position sensor
* Author(s): Noel Anderson

Implementation Notes
--------------------
**Hardware:**

* `AS5600 <https://ams.com/as5600>`

**Software and Dependencies:**

* Adafruit CircuitPython firmware for the supported boards: https://github.com/adafruit/circuitpython/releases
* Adafruit's Bus Device library: https://github.com/adafruit/Adafruit_CircuitPython_BusDevice
"""

from micropython import const
import adafruit_bus_device.i2c_device as i2c_device

# Register map & bit positions

_AS5600_DEFAULT_I2C_ADDR = const(0x36)
_REGISTER_ZMCO = const(0x00) # R
_REGISTER_ZPOS_HI = const(0x01) # R/W/P
_REGISTER_ZPOS_LO = const(0x02) # R/W/P
_REGISTER_MPOS_HI = const(0x03) # R/W/P
_REGISTER_MPOS_LO = const(0x04) # R/W/P
_REGISTER_MANG_HI = const(0x05) # R/W/P
_REGISTER_MANG_LO = const(0x06) # R/W/P

#---------------------------------------------------------------#
#   7   |   6   |   5   |   4   |   3   |   2   |   1   |   0   |
#-------+-------+-------+-------+-------+-------+-------+-------|
#       |       |   WD  |          FTH          |       SF      |
#---------------------------------------------------------------#
_REGISTER_CONF_HI = const(0x07) # R/W/P
_BIT_SF = const(0)
_BIT_FTH = const(2)
_BIT_WD = const(5)

#---------------------------------------------------------------#
#   7   |   6   |   5   |   4   |   3   |   2   |   1   |   0   |
#-------+-------+-------+-------+-------+-------+-------+-------|
#      PWMF     |     OUTS      |     HYST      |      PM       |
#---------------------------------------------------------------#
_REGISTER_CONF_LO = const(0x08) # R/W/P
_BIT_PM = const(0)
_BIT_HYST = const(2)
_BIT_OUTS = const(4)
_BIT_PWMF = const(6)

_REGISTER_RAW_ANGLE_HI = const(0x0C) # R
_REGISTER_RAW_ANGLE_LO = const(0x0D) # R
_REGISTER_ANGLE_HI = const(0x0E) # R
_REGISTER_ANGLE_LO = const(0x0F) # R

#---------------------------------------------------------------#
#   7   |   6   |   5   |   4   |   3   |   2   |   1   |   0   |
#-------+-------+-------+-------+-------+-------+-------+-------|
#       |       |   MD  |   ML  |   MH  |       |       |       |
#---------------------------------------------------------------#
_REGISTER_STATUS = const(0x0B)        # R
_STATUS_MH = const(0b00001000)
_STATUS_ML = const(0b00010000)
_STATUS_MD = const(0b00100000)
_STATUS_MASK = const(0b00111000)

_REGISTER_AGC = const(0x1A) # R
_REGISTER_MAGNITUDE_HI = const(0x1B) # R
_REGISTER_MAGNITUDE_LO = const(0x1C) # R
_REGISTER_BURN = const(0xFF) # W

# Commands

_BURN_ANGLE_COMMAND = const(0x80)
_BURN_SETTINGS_COMMAND = const(0x40)

_1_BIT = const(0b00000001)
_2_BITS = const(0b00000011)
_3_BITS = const(0b00000111)


# User-facing constants:

POWER_MODE_NOM = const(0)
POWER_MODE_LPM1 = const(1)
POWER_MODE_LPM2 = const(2)
POWER_MODE_LPM3 = const(3)

HYSTERESIS_OFF = const(0)
HYSTERESIS_1LSB = const(1)
HYSTERESIS_2LSB = const(2)
HYSTERESIS_3LSB = const(3)

OUTPUT_STAGE_ANALOG_FULL = const(0)
OUTPUT_STAGE_ANALOG_REDUCED = const(1)
OUTPUT_STAGE_DIGITAL_PWM = const(2)

PWM_FREQUENCY_115HZ = const(0)
PWM_FREQUENCY_230HZ = const(1)
PWM_FREQUENCY_460HZ = const(2)
PWM_FREQUENCY_920HZ = const(3)

SLOW_FILTER_16X = const(0)
SLOW_FILTER_8X = const(1)
SLOW_FILTER_4X = const(2)
SLOW_FILTER_2X = const(3)

FAST_FILTER_THRESHOLD_SLOW = const(0)
FAST_FILTER_THRESHOLD_6LSB = const(1)
FAST_FILTER_THRESHOLD_7LSB = const(2)
FAST_FILTER_THRESHOLD_9LSB = const(3)
FAST_FILTER_THRESHOLD_18LSB = const(4)
FAST_FILTER_THRESHOLD_21LSB = const(5)
FAST_FILTER_THRESHOLD_24LSB = const(6)
FAST_FILTER_THRESHOLD_10LSB = const(7)


class AS5600:
    """
    Initialise the PCA9955 chip at ``address`` on ``i2c_bus``.
    """
    def __init__(self, i2c, address=_AS5600_DEFAULT_I2C_ADDR):
        self._device = i2c_device.I2CDevice(i2c, address)

    # Output Registers

    @property
    def angle(self):
        """Get the current 12-bit angle (ANGLE)."""
        return self._read_16(_REGISTER_ANGLE_HI)

    @property
    def raw_angle(self):
        """Get the current unscaled and unmodified 12-bit angle (RAWANGLE)."""
        return self._read_16(_REGISTER_RAW_ANGLE_HI)

    # Status Registers

    @property
    def status(self) -> int:
        """Get the 8-bit status register (STATUS)."""
        return self._read_8(_REGISTER_STATUS) & _STATUS_MASK

    @property
    def is_magnet_too_strong(self) -> bool:
        """ Test MH Status Bit"""
        return bool(self.status & _STATUS_MH)

    @property
    def is_magnet_too_weak(self) -> bool:
        """ Test ML Status Bit"""
        return bool(self.status & _STATUS_ML)

    @property
    def is_magnet_detected(self) -> bool:
        """ Test MD Status Bit"""
        return bool(self.status & _STATUS_MD)

    @property
    def gain(self) -> int:
        """Get the 8-bit Automatic Gain Control value (AGC)."""
        return self._read_8(_REGISTER_AGC)

    @property
    def magnitude(self) -> int:
        """Get the 12-bit CORDIC magnitude (MAGNITUDE)."""
        return self._read_16(_REGISTER_MAGNITUDE_HI)

    # Configuration Registers

    @property
    def zmco(self) -> int:
        """Get the 8-bit burn count (ZMCO)."""
        return self._read_8(_REGISTER_ZMCO)

    @property
    def zero_position(self) -> int:
        """Get and set the 12-bit zero position (ZPOS)."""
        return self._read_16(_REGISTER_ZPOS_HI)

    @zero_position.setter
    def zero_position(self, value: int) -> int:
        if not 0 <= value <= 4095:
            raise ValueError("Value must be between 0 & 4095")
        return self._write_16(_REGISTER_ZPOS_HI, value)

    @property
    def max_position(self) -> int:
        """Get and set the 12-bit maximum position (MPOS)."""
        return self._read_16(_REGISTER_MPOS_HI)

    @max_position.setter
    def max_position(self, value: int) -> int:
        if not 0 <= value <= 4095:
            raise ValueError("Value must be between 0 & 4095")
        return self._write_16(_REGISTER_MPOS_HI, value)

    @property
    def max_angle(self) -> int:
        """Get and set the 12-bit maximum angle (MANG)."""
        return self._read_16(_REGISTER_MANG_HI)

    @max_angle.setter
    def max_angle(self, value: int) -> int:
        if not 0 <= value <= 4095:
            raise ValueError("Value must be between 0 & 4095")
        return self._write_16(_REGISTER_MANG_HI, value)

    @property
    def power_mode(self) -> int:
        """Get and set the Power Mode (PM) configuration."""
        return self._read_conf_register(_REGISTER_CONF_LO, _2_BITS, _BIT_PM)
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
